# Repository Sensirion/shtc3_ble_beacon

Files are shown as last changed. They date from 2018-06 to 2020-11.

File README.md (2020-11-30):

# SHTC3 BLE Beacon
Small CR2032 battery driven BLE beacon with Sensirion's humidity and temperature sensor

## Clone this repository
```
git clone --recursive https://github.com/Sensirion/shtc3_ble_beacon.git
```

## Repository content
* firmware (hex files and source code to program the microcontroller)
* schematics (schematics, PCB layout and gerber files)
* housing (STEP file for the housing parts)
* software (software to read out the beacon data with a Raspberry Pi)

## Firmware
The firmware is based on the example of nordics ble_app_beacon in their nRF SDK. So only the modified files are in this repository. 

* To create your own verison of the firmware install the nRF5 SDK v17 from nordic https://www.nordicsemi.com/Software-and-tools/Software/nRF5-SDK/Download#infotabs
* You might want to install the nRF command line tools as well to flash the firmware and the softdevice https://infocenter.nordicsemi.com/index.jsp?topic=%2Fug_nrf52840_dk%2FUG%2Fcommon%2Fnordic_tools.html
* In addition you have to install the arm cross compiler in version gcc-arm-none-eabi-7-2018-q2-update https://developer.arm.com/tools-and-software/open-source-software/developer-tools/gnu-toolchain/gnu-rm/downloads

Afterwards unzip the SDK. Go to the directory nRF5_SDK_17.0.2/examples/ble_peripheral/ble_app_beacon and replace the file "main.c" and add "shtc3.h" and "shtc3.c". Afterwards broswse the subfolder nRF5_SDK_17.0.2/examples/ble_peripheral/ble_app_beacon/pca10040/s132/config and replace the "sdk_config.h". 
As this example was tested with the armgcc replace the Makefile in the subfolder nRF5_SDK_17.0.2/examples/ble_peripheral/ble_app_beacon/pca10040/s132/armgcc.
If you prefer another compiler you have to include the following files to the example.
 * $(SDK_ROOT)/components/ble/ble_advertising/ble_advertising.c \
 * $(SDK_ROOT)/integration/nrfx/legacy/nrf_drv_twi.c \
 * $(SDK_ROOT)/modules/nrfx/drivers/src/nrfx_twi.c \
 * $(SDK_ROOT)/modules/nrfx/drivers/src/nrfx_twim.c \
 * $(PROJ_DIR)/shtc3.c \

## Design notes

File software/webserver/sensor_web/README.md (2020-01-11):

Raspberry Pi Control Panel
=========

The Raspberry Pi Control Panel is designed to give you a fast overview of your Raspberry Pi.

It was originally programmed to fit my needs, so if you need something else, you are free to add it yourself. I use it on RaspBMC,
i haven't testet it, but it should work on all other Raspbian/Debian based distributions.

Localizations can be created by adding files to
```
./localization/langugage.lang.php
```

and editing *index.php* by changing

```
define(LANGUAGE, "english");
```
to your languagefile.

**Preview:**



Tech
-----------

Raspberry Pi Control Panel includes some libraries. Libraries used are:

* [JustGage] - JavaScript library for the gauges.
* [Raphaël] - JavaScript library for vector graphics. Needed by JustGage.

Installation
--------------

You need to have a Webserver up and running on your Raspberry Pi. lighttpd, Apache2 have been testet, but i think others will do just fine. You need to have PHP enabled and be able to execute *shell_exec()* commmands.

For the reboot and shutdown buttons to work, you need to adjust your /etc/sudoers file by using
```sh
sudo visudo
```
and adding this line
```sh
www-data ALL=NOPASSWD:/sbin/shutdown
```
**WARNING:**
*After adding this line, the User www-data is able to restart and shutdown your Pi. Which means, anybody who might get access to your Pi over http could do so also. You need to secure it yourself. If your Pi is running in your local network, and there is nobody around who might shut down your Pi on purpose, this solution works fine without extra securing it.*

License
----

nada - do whatever you want. This was made quick and dirty, what means that this solution might work for me, but not for you. You may fork, rename, distribute, or do whatever you want, as long as you don't blame me for things getting broken or not working the way the should.

[JustGage]:http://justgage.com/
[Raphaël]:http://raphaeljs.com/

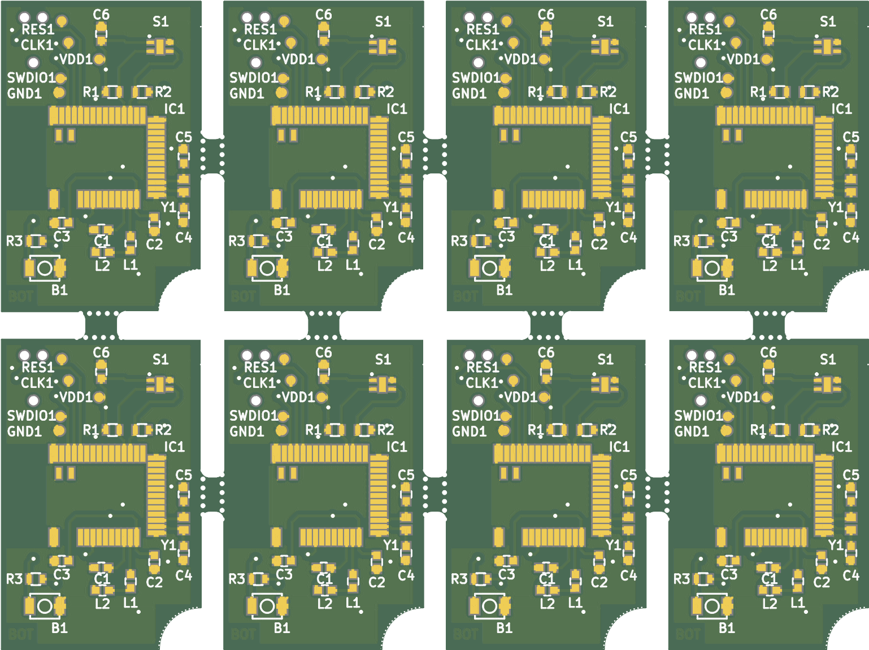
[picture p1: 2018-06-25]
schematic/gerber/panel_3by2/panel_4-2_Combined_Bottom.png

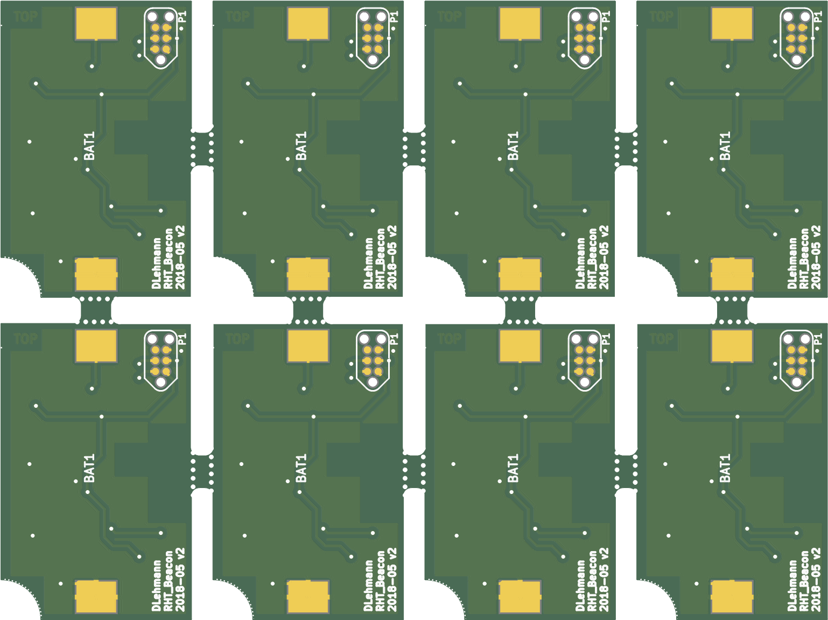
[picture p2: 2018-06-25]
schematic/gerber/panel_3by2/panel_4-2_Combined_Top.png

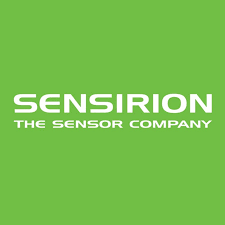
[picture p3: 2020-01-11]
software/webserver/sensor_web/images/raspberry.png

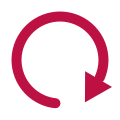
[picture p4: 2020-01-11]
software/webserver/sensor_web/images/reboot.gif

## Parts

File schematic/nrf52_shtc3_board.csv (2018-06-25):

Id | Designator | Package | Quantity | Designation | Supplier and ref
1 | S1 | DFN_4_pin_2x2 | 1 | SHTC3
2 | IC1 | RF_Module_42_pin | 1 | MDBT42Q_NRF52832
3 | B1 | SW_SPST_B3U-1000P | 1 | Omron Electronics Inc-EMC Div B3U-1000P
4 | BAT1 | BAT_Holder_2032 | 1 | MPD (Memory Protection Devices) BU2032SM-JJ-GTR
5 | Y1 | Crystal_1.6x1_2pad | 1 | Abracon LLC ABS05-32.768KHZ-9-T
6 | R1,R2,R3 | R_0603 | 3 | 10k
7 | CLK1 | WirePad_1mm_SMD | 1 | CLK
8 | GND1 | WirePad_1mm_SMD | 1 | GND
9 | RES1 | WirePad_1mm_SMD | 1 | RES
10 | SWDIO1 | WirePad_1mm_SMD | 1 | SWDIO
11 | VDD1 | WirePad_1mm_SMD | 1 | VDD
12 | P1 | TC2030-NL_SMALL | 1 | TC2030-CTX
13 | C1 | C_0603 | 1 | 1uF
14 | C2,C3 | C_0603 | 2 | 10uF
15 | C4,C5 | C_0603 | 2 | 12pF
16 | C6 | C_0603 | 1 | 100nF
17 | L1 | C_0603 | 1 | 10uH
18 | L2 | C_0603 | 1 | 15nH

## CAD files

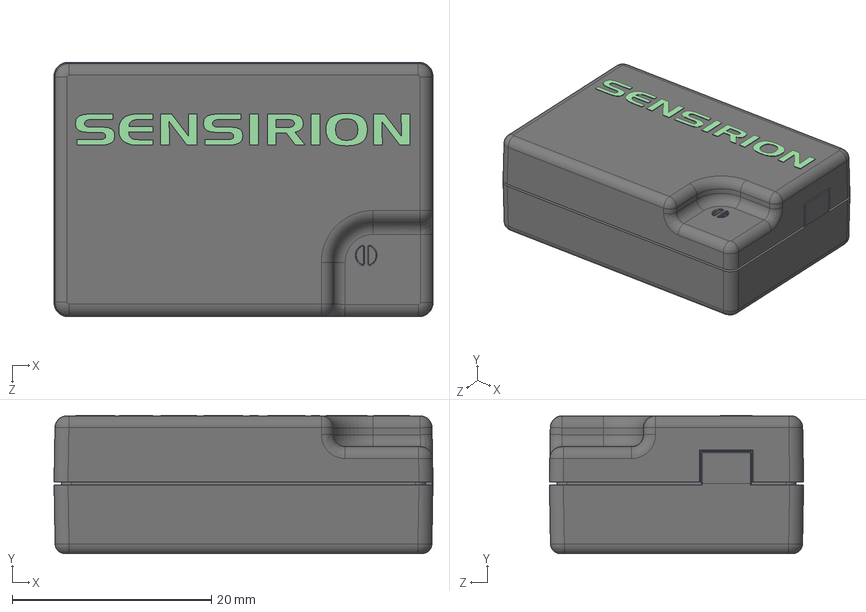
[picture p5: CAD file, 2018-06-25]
housing/131020-_SHTC3 Beacon.STEP
38.0 x 13.9 x 25.5 mm
02_Senkschraube mit Innensechskant ISO 10642_M02x12
02_Sechskantmutter 0.5d ISO 4035_M02
mag_15083496_4x1_O_Ring

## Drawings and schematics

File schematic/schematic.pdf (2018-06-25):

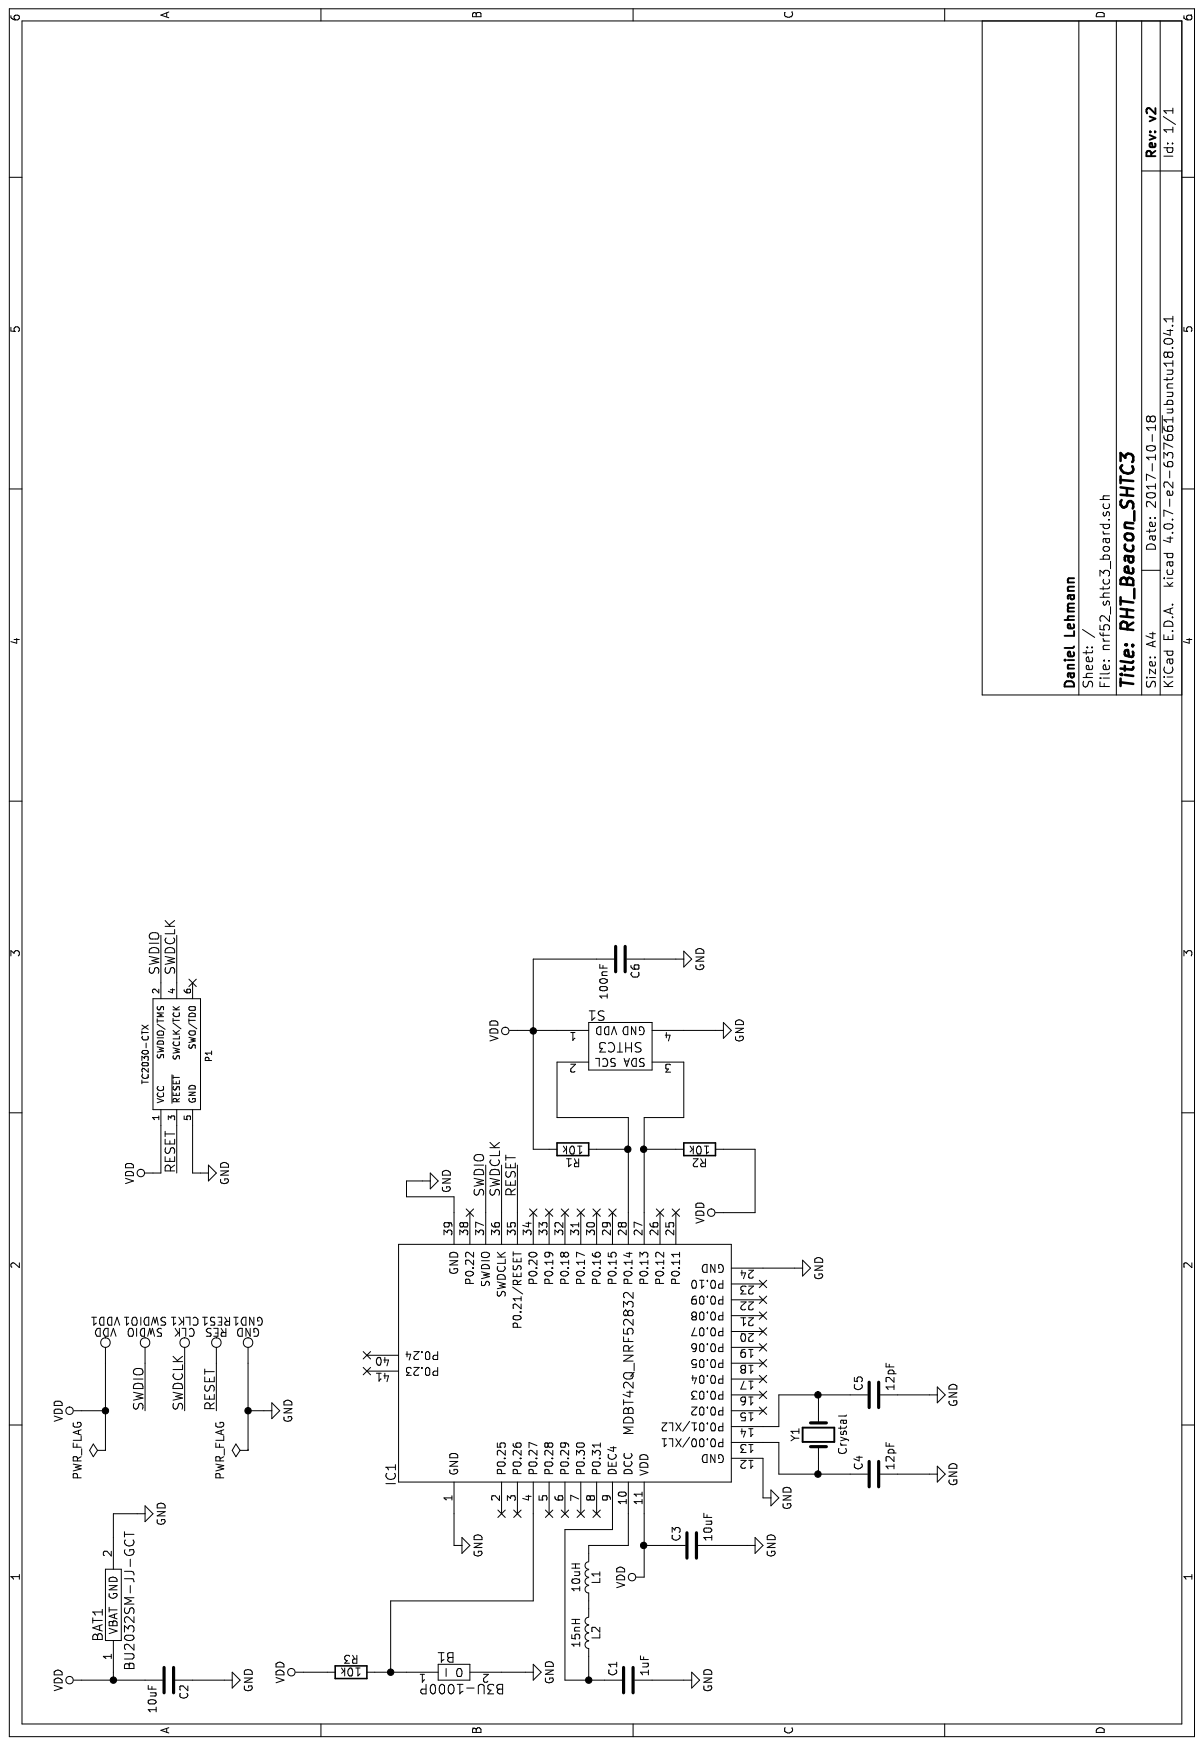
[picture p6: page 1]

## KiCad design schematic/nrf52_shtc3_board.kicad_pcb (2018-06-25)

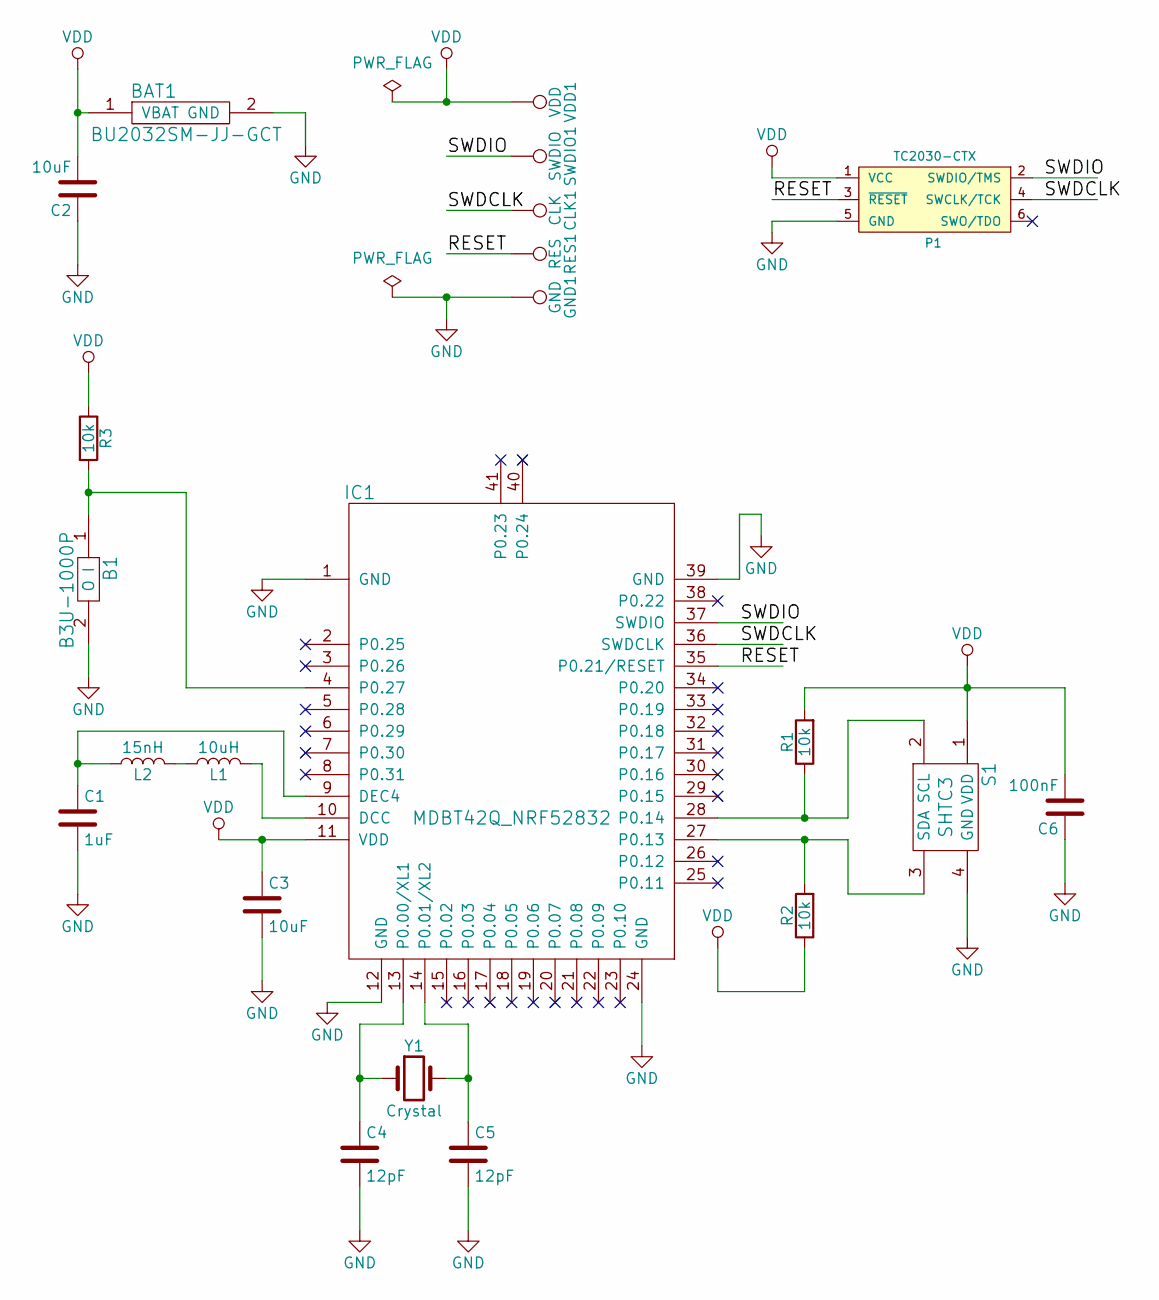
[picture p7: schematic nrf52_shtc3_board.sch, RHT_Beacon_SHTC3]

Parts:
B1: B3U-1000P; SW_SPST_B3U-1000P
BAT1: BU2032SM-JJ-GCT; BAT_Holder_2032
C1: 1uF; C_0603
C2, C3: 10uF; C_0603
C4, C5: 12pF; C_0603
C6: 100nF; C_0603
CLK1: CLK; WirePad_1mm_SMD
GND1: GND; WirePad_1mm_SMD
IC1: MDBT42Q_NRF52832; RF_Module_42_pin
L1: 10uH; C_0603
L2: 15nH; C_0603
P1: TC2030-CTX; TC2030-NL_SMALL
R1, R2, R3: 10k; R_0603
RES1: RES; WirePad_1mm_SMD
S1: SHTC3; DFN_4_pin_2x2
SWDIO1: SWDIO; WirePad_1mm_SMD
VDD1: VDD; WirePad_1mm_SMD
Y1: Crystal; Crystal_1.6x1_2pad

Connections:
/RESET: IC1.35 (P0.21/RESET), P1.3 (~RESET~), RES1.1
/SWDCLK: CLK1.1, IC1.36 (SWDCLK), P1.4 (SWCLK/TCK)
/SWDIO: IC1.37 (SWDIO), P1.2 (SWDIO/TMS), SWDIO1.1
GND: B1.2 (O), BAT1.2 (GND), C1.2, C2.1, C3.2, C4.2, C5.2, C6.1, GND1.1, IC1.1 (GND), IC1.12 (GND), IC1.24 (GND), IC1.39 (GND), P1.5 (GND), S1.4 (GND)
unnamed: B1.1 (I), IC1.4 (P0.27), R3.2
unnamed: C1.1, IC1.9 (DEC4), L2.1
unnamed: C4.1, IC1.13 (P0.00/XL1), Y1.1
unnamed: C5.1, IC1.14 (P0.01/XL2), Y1.2
unnamed: IC1.10 (DCC), L1.2
unnamed: IC1.27 (P0.13), R2.2, S1.3 (SDA)
unnamed: IC1.28 (P0.14), R1.1, S1.2 (SCL)
unnamed: L1.1, L2.2
VDD: BAT1.1 (VBAT), C2.2, C3.1, C6.2, IC1.11 (VDD), P1.1 (VCC), R1.2, R2.1, R3.1, S1.1 (VDD), VDD1.1

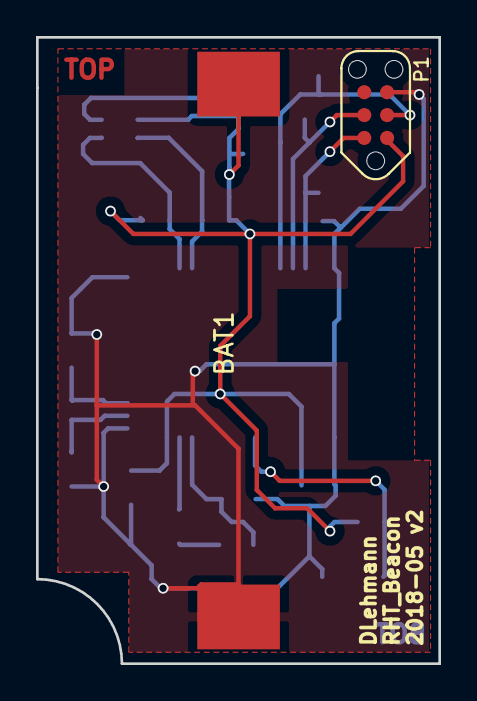
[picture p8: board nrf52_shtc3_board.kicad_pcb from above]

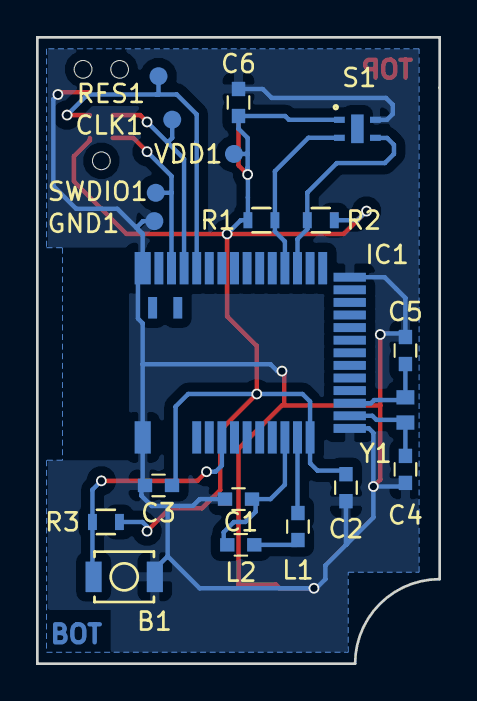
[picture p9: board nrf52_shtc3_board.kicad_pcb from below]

Board: 2 copper layers, 22.4 x 34.8 mm, 22 parts (20 on the bottom side), 13 nets.

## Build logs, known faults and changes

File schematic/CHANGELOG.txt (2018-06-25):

2017-10 Initial Version 1.0

2018-05-21 Version 2.0
- Move SHT to get area around for sealing
- Move C6 to free area for sealing
- Add Edge in EdgeCut for Screw in Housing
- Change battery from 1632 to 2032
- Add programmer port Tag Connect TC2030 IDC NL for Cortex Pinout
- Add some 3D models
- Relocate manual solder pads
- Relocate Silk Screen

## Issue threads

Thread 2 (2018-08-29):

Readout Software described in README is Missing

travc, 2018-08-29:
I'd love to see some code (python preferably) to receive the data on a Raspberry Pi as described in the Readme.

abrauchli, 2018-09-17:
Hi @travc thanks for the report. Kindly note that the person in charge internally is currently out of office so it might take a few weeks.

@Fototux it's indeed described in the readme that there should be software, do we have anything we can hand out or should we fix the readme?

travc, 2018-11-14:
I have a very small script using the pygatt which gets one-shot reads of temperature, humidity, and battery.  It is pretty slow, you have to supply the device address (no scanning), and I haven't bothered to figure out how to grab the logs off of the gadget... But it is something.
https://github.com/travc/pihvac/blob/master/smartgadgetBLEread.py

ojousima, 2019-05-24:
It's been a while, but I'd love to see the software part :)

Fototux, 2020-01-09:
Sorry for the late answer. I started this as a private project and didn't had the time to proceed so far. I just added the script I use for reading the BLE data to the the repo
https://github.com/Sensirion/shtc3_ble_beacon/tree/master/software

Closed 2020-01-09.

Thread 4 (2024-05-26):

Updating old python beacon reader to modern bleak package - temperature encoding of the BLE characteristics ?

markdoerr, 2024-05-26:
Hallo Sensiron Beacon developers,

for a student demonstration project, I tried to write an updated version of the Bluetooth readout of SHT31 beacon (blescan.py) with the modern python *bleak* package, since the original bluetooth python package is outdated:

```
import asyncio
from bleak import BleakClient

BLE_DEVICE_MAC_ADDRESS = "E4:A0:36:CA:7B:7E" # BLE_DEVICE_MAC_ADDRESS of the device (beacon)
TEMPERATURE_UUID = "00001234-b38d-4985-720e-0f993a68ee41"
TEMPERATURE_HANDLE = 49

def calculate_temperature(data):
    print("temp:", data, type(data))
    print("== temp - calc : ", (data / 65536.) * 175. - 45)

async def main(BLE_DEVICE_MAC_ADDRESS):
    async with BleakClient(BLE_DEVICE_MAC_ADDRESS) as client:

        services = client.services
        
        for service in services:
            for char in service.characteristics:
                print("--->", char.handle)
                if char.handle == TEMPERATURE_HANDLE : # TEMPERATURE_UUID :
                    char_data = await client.read_gatt_char(char.uuid)
                    print("temperature raw:", char_data, type(char_data), len(char_data))

                    temp_data = int.from_bytes(char_data, byteorder='little') # which bytes contain the temperature value?

                    calculate_temperature(temp_data)

asyncio.run(main(BLE_DEVICE_MAC_ADDRESS))
```

But I am stuck with the line extracting temp_data, because it is not clear to me, what part of the 4 byte array returning as char_data does really contain the temperature information which could be then converted as described in the documentation to deg. celsius (with the above formula). Could you please help ? Thanks a lot in advance.

LeonieFierz, 2024-05-27:
Hi @markdoerr

You can see in the firmware implementation how the data is encoded. Refer to https://github.com/Sensirion/shtc3_ble_beacon/blob/master/firmware/main.c, advertising_update.
The first two byte 0 and 1 are temperature ticks (uint16), byte 2 and 3 humidity ticks (uint16) and the byteorder is big endian. So I suggest the following line of code (not tested):

 `temp_ticks = int.from_bytes(char_data[0,2], byteorder='big') `

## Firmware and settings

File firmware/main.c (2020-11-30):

/**
 * Copyright (c) 2014 - 2020, Nordic Semiconductor ASA
 *
 * All rights reserved.
 *
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
 * 3. Neither the name of Nordic Semiconductor ASA nor the names of its
 *    contributors may be used to endorse or promote products derived from this
 *    software without specific prior written permission.
 *
 * 4. This software, with or without modification, must only be used with a
 *    Nordic Semiconductor ASA integrated circuit.
 *
 * 5. Any software provided in binary form under this license must not be reverse
 *    engineered, decompiled, modified and/or disassembled.
 *
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
 */
/** @file
 *
 * @defgroup ble_sdk_app_beacon_main main.c
 * @{
 * @ingroup ble_sdk_app_beacon
 * @brief Beacon Transmitter Sample Application main file.
 *
 * This file contains the source code for an Beacon transmitter sample application.
 */

#include <stdbool.h>
#include <stdint.h>
#include "nordic_common.h"
#include "bsp.h"
#include "nrf_soc.h"
#include "nrf_sdh.h"
#include "nrf_sdh_ble.h"
#include "ble_advdata.h"
#include "app_timer.h"
#include "nrf_pwr_mgmt.h"

#include "nrf_log.h"
#include "nrf_log_ctrl.h"
#include "nrf_log_default_backends.h"

#include "nrf_delay.h"
#include "shtc3.h"

#define APP_BLE_CONN_CFG_TAG            1                                  /**< A tag identifying the SoftDevice BLE configuration. */

#define NON_CONNECTABLE_ADV_INTERVAL    MSEC_TO_UNITS(2000, UNIT_0_625_MS)  /**< The advertising interval for non-connectable advertisement (100 ms). This value can vary between 100ms to 10.24s). */

#define APP_BEACON_INFO_LENGTH          0x17                               /**< Total length of information advertised by the Beacon. */
#define APP_ADV_DATA_LENGTH             0x15                               /**< Length of manufacturer specific data in the advertisement. */
#define APP_DEVICE_TYPE                 0x02                               /**< 0x02 refers to Beacon. */
#define APP_MEASURED_RSSI               0xC3                               /**< The Beacon's measured RSSI at 1 meter distance in dBm. */
#define APP_COMPANY_IDENTIFIER          0x0059                             /**< Company identifier for Nordic Semiconductor ASA. as per www.bluetooth.org. */
#define APP_MAJOR_VALUE                 0x00, 0x01                         /**< Major value used to identify Beacons. */
#define APP_MINOR_VALUE                 0x00, 0x01                         /**< Minor value used to identify Beacons. */
#define APP_BEACON_UUID                 0x13, 0x31, 0xDD, 0xEE, \
                                        0x13, 0x06, 0x29, 0x06, \
                                        0x82, 0x83, 0x28, 0x07            /**< UUID for Beacon. */

#define DEAD_BEEF                       0xDEADBEEF                         /**< Value used as error code on stack dump, can be used to identify stack location on stack unwind. */

#define MAJ_VAL_OFFSET_IN_BEACON_INFO   25                                 /**< Position of the MSB of the Major Value in **/

#define DEVICE_NAME                     "RHT_DA"

static ble_gap_adv_params_t m_adv_params;                                  /**< Parameters to be passed to the stack when starting advertising. */
static uint8_t              m_adv_handle = BLE_GAP_ADV_SET_HANDLE_NOT_SET; /**< Advertising handle used to identify an advertising set. */
static uint8_t              m_enc_advdata[BLE_GAP_ADV_SET_DATA_SIZE_MAX];  /**< Buffer for storing an encoded advertising set. */

static ble_advdata_t advdata;

APP_TIMER_DEF(m_sensor_timer_id);

/**@brief Struct that contains pointers to the encoded advertising data. */
static ble_gap_adv_data_t m_adv_data =
{
    .adv_data =
    {
        .p_data = m_enc_advdata,
        .len    = BLE_GAP_ADV_SET_DATA_SIZE_MAX
    },
    .scan_rsp_data =
    {
        .p_data = NULL,
        .len    = 0

    }
};


static uint8_t m_beacon_info[APP_BEACON_INFO_LENGTH] =                    /**< Information advertised by the Beacon. */
{
    APP_DEVICE_TYPE,     // Manufacturer specific information. Specifies the device type in this
                         // implementation.
    APP_ADV_DATA_LENGTH, // Manufacturer specific information. Specifies the length of the
                         // manufacturer specific data in this implementation.
    APP_BEACON_UUID,     // 128 bit UUID value.
    APP_MAJOR_VALUE,     // Major arbitrary value that can be used to distinguish between Beacons.
    APP_MINOR_VALUE,     // Minor arbitrary value that can be used to distinguish between Beacons.
    APP_MEASURED_RSSI    // Manufacturer specific information. The Beacon's measured TX power in
                         // this implementation.
};

static ret_code_t read_sensor_data(uint16_t* humidity, uint16_t* temperature)
{
    uint16_t hum=0;
    uint16_t tem=0;
    ret_code_t err_code;

    shtc3_start_measurement();
    // wait for 12.1 ms for measurement results
    nrf_delay_ms(13);
    shtc3_read_measurement();
    err_code = shtc3_get_rht_raw(&hum, &tem);
    *humidity = hum;
    *temperature = tem;
    
    return err_code;
}

/**@brief Callback function for asserts in the SoftDevice.
 *
 * @details This function will be called in case of an assert in the SoftDevice.
 *
 * @warning This handler is an example only and does not fit a final product. You need to analyze
 *          how your product is supposed to react in case of Assert.
 * @warning On assert from the SoftDevice, the system can only recover on reset.
 *
 * @param[in]   line_num   Line number of the failing ASSERT call.
 * @param[in]   file_name  File name of the failing ASSERT call.
 */
void assert_nrf_callback(uint16_t line_num, const uint8_t * p_file_name)
{
    app_error_handler(DEAD_BEEF, line_num, p_file_name);
}

/**@brief Function for initializing the Advertising functionality.
 *
 * @details Encodes the required advertising data and passes it to the stack.
 *          Also builds a structure to be passed to the stack when starting advertising.
 */
static void advertising_init(void)
{
    uint32_t      err_code;
    uint8_t       flags = BLE_GAP_ADV_FLAG_BR_EDR_NOT_SUPPORTED;

    ble_advdata_manuf_data_t manuf_specific_data;
    manuf_specific_data.company_identifier = APP_COMPANY_IDENTIFIER;

    manuf_specific_data.data.p_data = (uint8_t *) m_beacon_info;
    manuf_specific_data.data.size   = APP_BEACON_INFO_LENGTH;

    // Build and set advertising data.
    memset(&advdata, 0, sizeof(advdata));

    advdata.name_type             = BLE_ADVDATA_NO_NAME;
    //advdata.name_type             = BLE_ADVDATA_SHORT_NAME;
    //advdata.short_name_len        = 6;
    advdata.flags                 = flags;
    advdata.p_manuf_specific_data = &manuf_specific_data;

    // Initialize advertising parameters (used when starting advertising).
    memset(&m_adv_params, 0, sizeof(m_adv_params));

    m_adv_params.properties.type = BLE_GAP_ADV_TYPE_NONCONNECTABLE_NONSCANNABLE_UNDIRECTED;
    m_adv_params.p_peer_addr     = NULL;    // Undirected advertisement.
    m_adv_params.filter_policy   = BLE_GAP_ADV_FP_ANY;
    m_adv_params.interval        = NON_CONNECTABLE_ADV_INTERVAL;
    m_adv_params.duration        = 0;       // Never time out.

    err_code = ble_advdata_encode(&advdata, m_adv_data.adv_data.p_data, &m_adv_data.adv_data.len);
    APP_ERROR_CHECK(err_code);

    err_code = sd_ble_gap_adv_set_configure(&m_adv_handle, &m_adv_data, &m_adv_params);
    APP_ERROR_CHECK(err_code);
}


/**@brief Function for starting advertising.
 */
static void advertising_start(void)
{
    ret_code_t err_code;

    err_code = sd_ble_gap_adv_start(m_adv_handle, APP_BLE_CONN_CFG_TAG);
    APP_ERROR_CHECK(err_code);

    err_code = bsp_indication_set(BSP_INDICATE_ADVERTISING);
    APP_ERROR_CHECK(err_code);
}

static void advertising_update(void)
{
    uint16_t temperature_raw;
    uint16_t humidity_raw;
    uint8_t index = MAJ_VAL_OFFSET_IN_BEACON_INFO;

    read_sensor_data(&humidity_raw, &temperature_raw);
    NRF_LOG_INFO("RH: %i, T: %i", humidity_raw, temperature_raw);

    m_adv_data.adv_data.p_data[index++] = temperature_raw >> 8;
    m_adv_data.adv_data.p_data[index++] = temperature_raw;

    m_adv_data.adv_data.p_data[index++] = humidity_raw >> 8;
    m_adv_data.adv_data.p_data[index++] = humidity_raw;
}

/**@brief Function for initializing the BLE stack.
 *
 * @details Initializes the SoftDevice and the BLE event interrupt.
 */
static void ble_stack_init(void)
{
    ret_code_t err_code;

    err_code = nrf_sdh_enable_request();
    APP_ERROR_CHECK(err_code);

    // Configure the BLE stack using the default settings.
    // Fetch the start address of the application RAM.
    uint32_t ram_start = 0;
    err_code = nrf_sdh_ble_default_cfg_set(APP_BLE_CONN_CFG_TAG, &ram_start);
    APP_ERROR_CHECK(err_code);

    // Enable BLE stack.
    err_code = nrf_sdh_ble_enable(&ram_start);
    APP_ERROR_CHECK(err_code);
}


/**@brief Function for initializing logging. */
static void log_init(void)
{
    ret_code_t err_code = NRF_LOG_INIT(NULL);
    APP_ERROR_CHECK(err_code);

    NRF_LOG_DEFAULT_BACKENDS_INIT();
}

/**@brief Function for timeout handlder to call sensor update. */
static void timer_callback_handler(void * p_context)
{
    UNUSED_PARAMETER(p_context);
    advertising_update();
}

/**@brief Function for initializing timers. */
static void timers_init(void)
{
    ret_code_t err_code = app_timer_init();
    APP_ERROR_CHECK(err_code);

    err_code = app_timer_create(&m_sensor_timer_id,
                                APP_TIMER_MODE_REPEATED,
                                timer_callback_handler);
}

/**@brief Function for starting timers. */
static void application_timers_start(void)
{
    uint32_t err_code;

    err_code = app_timer_start(m_sensor_timer_id, APP_TIMER_TICKS(2000), NULL);
    APP_ERROR_CHECK(err_code);
}

/**@brief Function for initializing power management.
 */
static void power_management_init(void)
{
    ret_code_t err_code;
    err_code = nrf_pwr_mgmt_init();
    APP_ERROR_CHECK(err_code);
}


/**@brief Function for handling the idle state (main loop).
 *
 * @details If there is no pending log operation, then sleep until next the next event occurs.
 */
static void idle_state_handle(void)
{

    if (NRF_LOG_PROCESS() == false)
    {
        nrf_pwr_mgmt_run();
    }
}


/**
 * @brief Function for application main entry.
 */
int main(void)
{
    uint16_t temperature_raw;
    uint16_t humidity_raw;

    // Initialize.
    log_init();
    timers_init();
    power_management_init();
    ble_stack_init();

    sd_power_dcdc_mode_set(NRF_POWER_DCDC_ENABLE);

    advertising_init();
    NRF_LOG_INFO("TWI start.");
    twi_init();

    // test sensor read 
    read_sensor_data(&humidity_raw, &temperature_raw);
    NRF_LOG_INFO("RH: %i, T: %i", humidity_raw, temperature_raw);

    // Start execution.
    NRF_LOG_INFO("Beacon example started.");
    advertising_start();
    application_timers_start();

    // Enter main loop.
    for (;; )
    {
        idle_state_handle();
    }
}

/**
 * @}
 */
